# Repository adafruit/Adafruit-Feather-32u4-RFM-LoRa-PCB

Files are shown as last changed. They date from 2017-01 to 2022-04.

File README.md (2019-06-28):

## Adafruit Feather 32u4 RFM LoRa Radios PCB

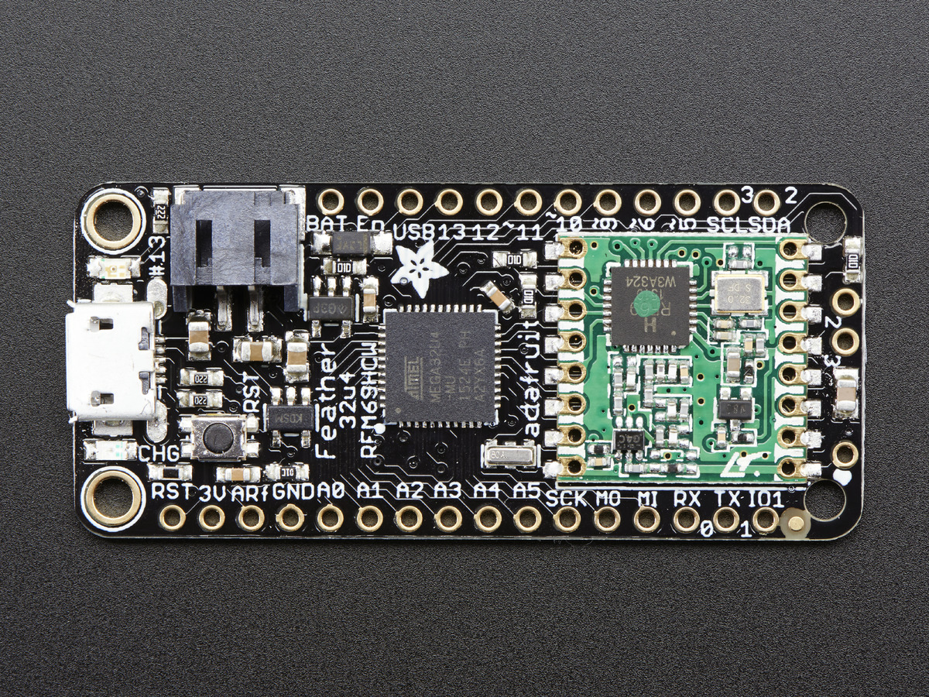
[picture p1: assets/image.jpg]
<br/>
Click below to purchase one from the Adafruit shop

PCB files for the Adafruit Feather 32u4 RFM69 and LoRa Radio. Format is EagleCAD schematic and board layout

For more details, check out the product pages at
* RFM69HCW Packet Radio - 868 or 915 MHz https://www.adafruit.com/product/3076
* RFM69HCW Packet Radio - 433MHz https://www.adafruit.com/product/3077
* RFM95 LoRa Radio- 868 or 915 MHz https://www.adafruit.com/product/3078
* RFM96 LoRa Radio - 433MHz https://www.adafruit.com/product/3079

### Description

We call these RadioFruits, our take on an microcontroller packet radio transceiver with built in USB and battery charging. Its an Adafruit Feather 32u4 with a radio module cooked in! Great for making wireless networks that can go further than 2.4GHz 802.15.4 and similar, are more flexible than Bluetooth LE and without the high power requirements of WiFi.

Feather is the new development board from Adafruit, and like its namesake it is thin, light, and lets you fly! We designed Feather to be a new standard for portable microcontroller cores.

### License

Adafruit invests time and resources providing this open source design, please support Adafruit and open-source hardware by purchasing products from [Adafruit](https://www.adafruit.com)!

Designed by Limor Fried/Ladyada for Adafruit Industries.

Creative Commons Attribution/Share-Alike, all text above must be included in any redistribution. See license.txt for additional details.

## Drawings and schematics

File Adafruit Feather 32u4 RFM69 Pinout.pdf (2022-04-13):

# Adafruit Feather 32u4 RFM69 433/900MHz

# https://www.adafruit.com/products/3076

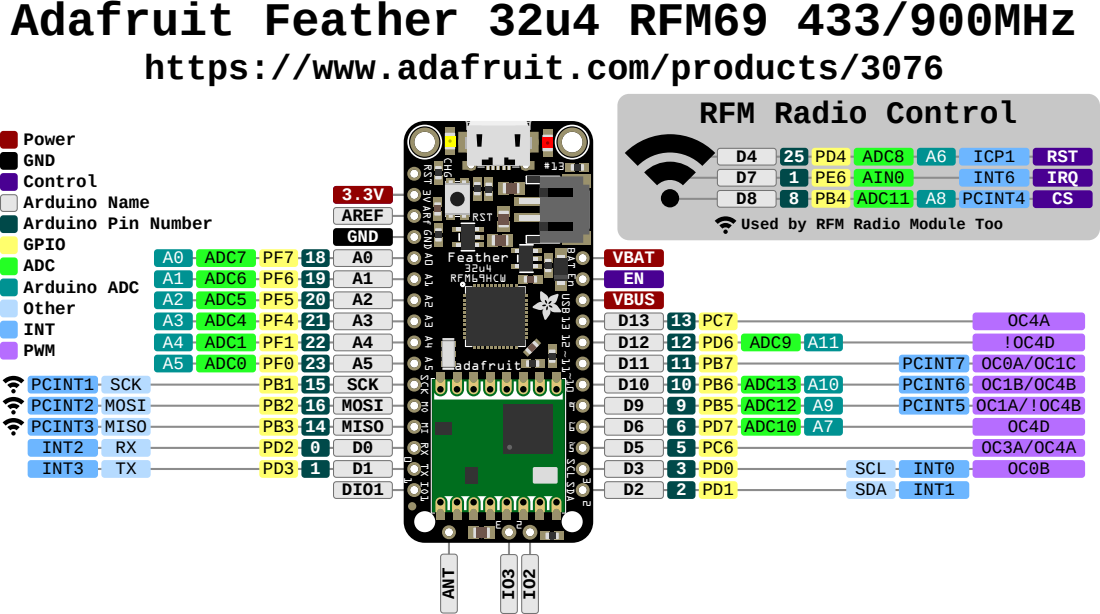
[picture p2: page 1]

Used by RFM Radio Module Too

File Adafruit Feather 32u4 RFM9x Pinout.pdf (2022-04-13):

# Adafruit Feather 32u4 RFM9x LoRa

# https://www.adafruit.com/products/3078

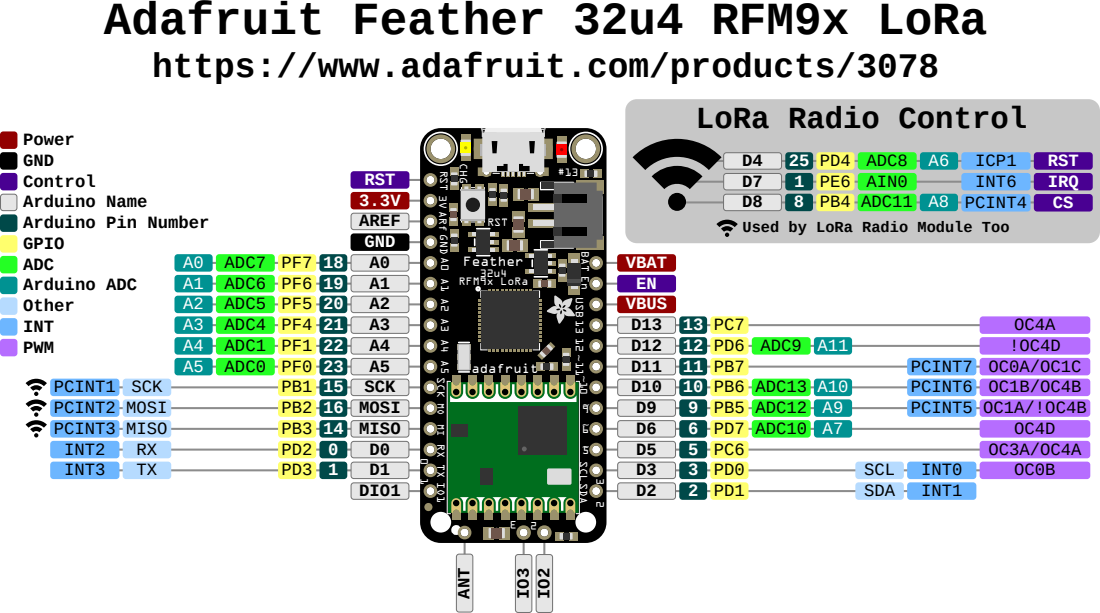
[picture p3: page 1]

Used by LoRa Radio Module Too

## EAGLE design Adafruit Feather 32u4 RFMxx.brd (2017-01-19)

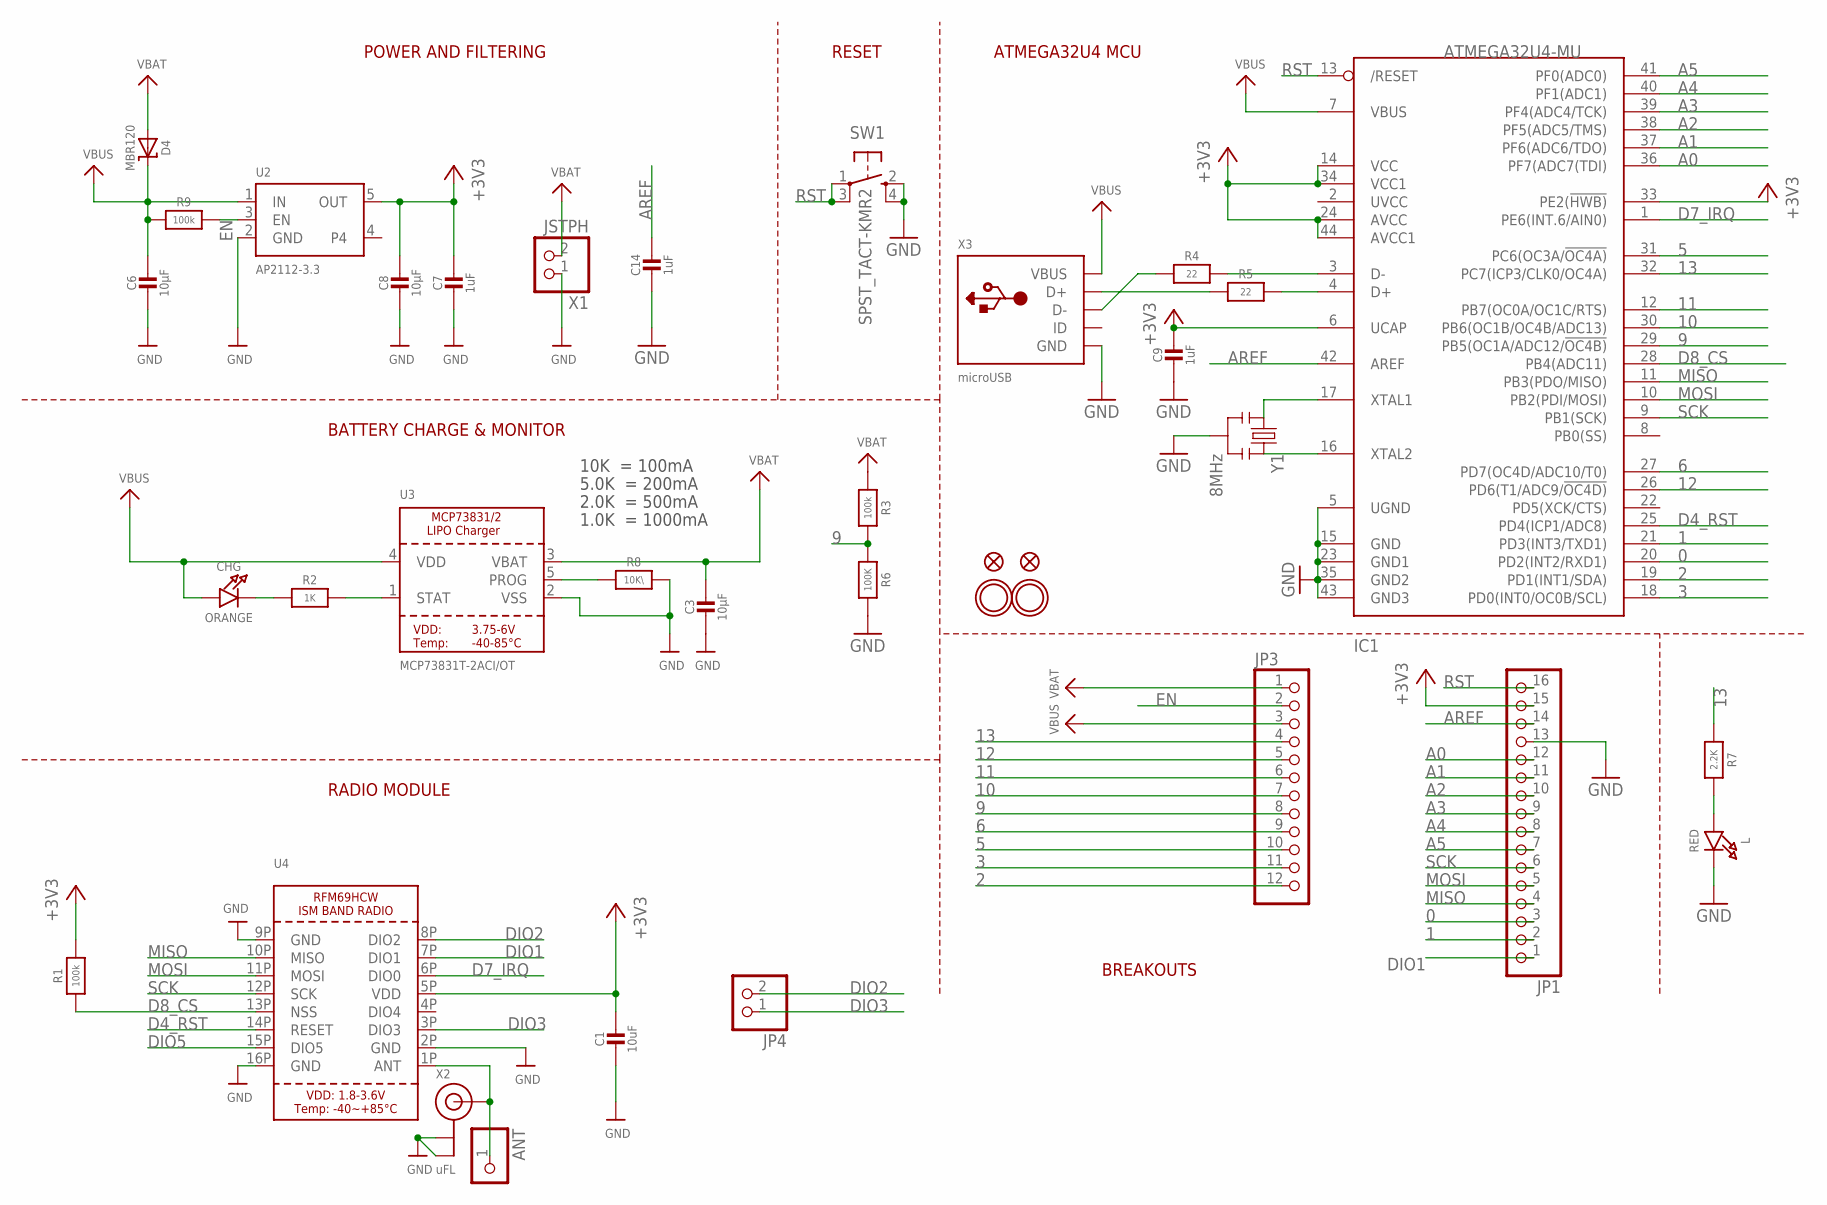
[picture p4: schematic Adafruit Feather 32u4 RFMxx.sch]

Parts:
ANT: HEADER-1X1ROUND; 1X01_ROUND
C1: 10uF; 0805-NO
C3, C6, C8: 10µF; 0805-NO
C7, C14: 1uF; 0603-NO
C9: 1uF; _0603MP
CHG: ORANGE; CHIPLED_0805_NOOUTLINE
D4: MBR120; SOD-123
IC1: ATMEGA32U4-MU; TQFN44_7MM
JP1: HEADER-1X16ROUND; 1X16_ROUND
JP3: HEADER-1X12; 1X12_ROUND
JP4: HEADER-1X2ROUND; 1X02_ROUND
L: RED; CHIPLED_0805_NOOUTLINE
R1, R3, R9: 100k; 0603-NO
R2: 1K; 0603-NO
R4, R5: 22; 0603-NO
R6: 100K; 0603-NO
R7: 2.2K; 0603-NO
R8: 10K\; 0603-NO
SW1: SPST_TACT-KMR2; KMR2
U2: AP2112-3.3; SOT23-5
U3: MCP73831T-2ACI/OT; SOT23-5
U4: RFM69HCW_SMT; RFMHCW_SMT
U$31, U$32: MOUNTINGHOLE2.5; MOUNTINGHOLE_2.5_PLATED
U$34, U$35: FIDUCIAL""; FIDUCIAL_1MM
X1: JSTPH; JSTPH2
X2: uFL; U.FL
X3: microUSB; 4UCONN_20329_V2
Y1: 8MHz; RESONATOR-SMD

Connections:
0: IC1.20 (PD2(INT2/RXD1)), JP1.3
1: IC1.21 (PD3(INT3/TXD1)), JP1.2
2: IC1.19 (PD1(INT1/SDA)), JP3.12
3: IC1.18 (PD0(INT0/OC0B/SCL)), JP3.11
5: IC1.31 (PC6(OC3A/!OC4A)), JP3.10
6: IC1.27 (PD7(OC4D/ADC10/T0)), JP3.9
9: IC1.29 (PB5(OC1A/ADC12/!OC4B)), JP3.8, R3.2, R6.1
10: IC1.30 (PB6(OC1B/OC4B/ADC13)), JP3.7
11: IC1.12 (PB7(OC0A/OC1C/RTS)), JP3.6
12: IC1.26 (PD6(T1/ADC9/!OC4D)), JP3.5
13: IC1.32 (PC7(ICP3/CLK0/OC4A)), JP3.4, R7.1
+3V3: C1.1, C7.1, C8.1, C9.1, IC1.6 (UCAP), IC1.14 (VCC), IC1.24 (AVCC), IC1.33 (PE2(!HWB)), IC1.34 (VCC1), IC1.44 (AVCC1), JP1.15, R1.2, U2.5 (OUT), U4.5P (VDD)
A0: IC1.36 (PF7(ADC7(TDI)), JP1.12
A1: IC1.37 (PF6(ADC6/TDO)), JP1.11
A2: IC1.38 (PF5(ADC5/TMS)), JP1.10
A3: IC1.39 (PF4(ADC4/TCK)), JP1.9
A4: IC1.40 (PF1(ADC1)), JP1.8
A5: IC1.41 (PF0(ADC0)), JP1.7
ANT: ANT.1, U4.1P (ANT), X2.3 (SIGNAL)
AREF: C14.1, IC1.42 (AREF), JP1.14
D4_RST: IC1.25 (PD4(ICP1/ADC8)), U4.14P (RESET)
D7_IRQ: IC1.1 (PE6(INT.6/AIN0)), U4.6P (DIO0)
D8_CS: IC1.28 (PB4(ADC11)), R1.1, U4.13P (NSS)
D+: IC1.4 (D+), R5.2
D-: IC1.3 (D-), R4.2
DIO1: JP1.1, U4.7P (DIO1)
DIO2: JP4.2, U4.8P (DIO2)
DIO3: JP4.1, U4.3P (DIO3)
DIO5: U4.15P (DIO5)
EN: JP3.2, R9.2, U2.3 (EN)
GND: C1.2, C3.2, C6.2, C7.2, C8.2, C9.2, C14.2, IC1.5 (UGND), IC1.15 (GND), IC1.23 (GND1), IC1.35 (GND2), IC1.43 (GND3), JP1.13, L.C, R6.2, R8.2, SW1.2 (S), SW1.4 (S1), U2.2 (GND), U3.2 (VSS), U4.2P (GND), U4.9P (GND), U4.16P (GND), X1.1, X2.1 (GND), X2.2 (GND), X3.BASE@1 (GND), X3.BASE@2 (GND), X3.GND, X3.SPRT@1 (GND), X3.SPRT@2 (GND), X3.SPRT@3 (GND), X3.SPRT@4 (GND), Y1.2
MISO: IC1.11 (PB3(PDO/MISO)), JP1.4, U4.10P (MISO)
MOSI: IC1.10 (PB2(PDI/MOSI)), JP1.5, U4.11P (MOSI)
unnamed: CHG.C, R2.1
unnamed: L.A, R7.2
unnamed: R2.2, U3.1 (STAT)
unnamed: R8.1, U3.5 (PROG)
unnamed: IC1.16 (XTAL2), Y1.3
unnamed: IC1.17 (XTAL1), Y1.1
unnamed: R5.1, X3.D+
unnamed: R4.1, X3.D-
RST: IC1.13 (/RESET), JP1.16, SW1.1, SW1.3 (P1)
SCK: IC1.9 (PB1(SCK)), JP1.6, U4.12P (SCK)
VBAT: C3.1, D4.A, JP3.1, R3.1, U3.3 (VBAT), X1.2
VBUS: C6.1, CHG.A, D4.C, IC1.7 (VBUS), JP3.3, R9.1, U2.1 (IN), U3.4 (VDD), X3.VBUS

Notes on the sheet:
POWER AND FILTERING
RESET
ATMEGA32U4 MCU
10K = 100mA
5.0K = 200mA
2.0K = 500mA
1.0K = 1000mA
BATTERY CHARGE & MONITOR
BREAKOUTS
RADIO MODULE

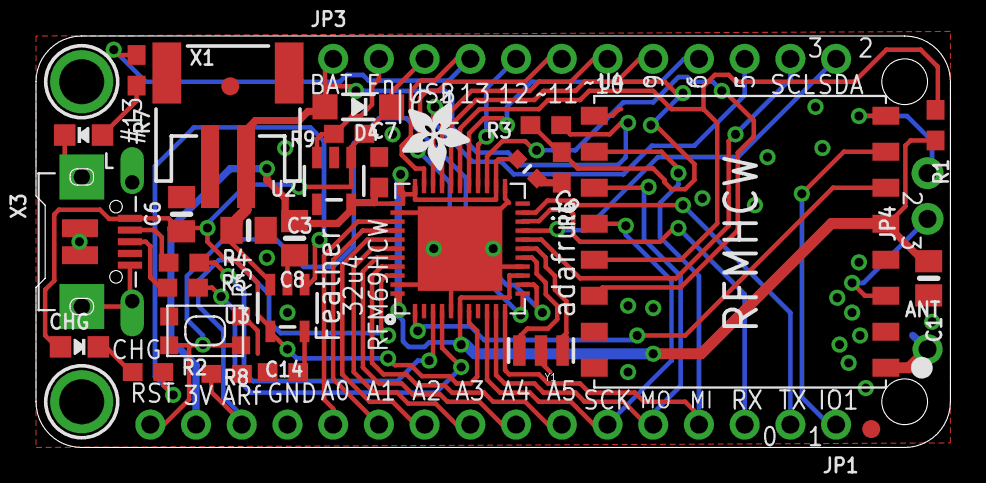
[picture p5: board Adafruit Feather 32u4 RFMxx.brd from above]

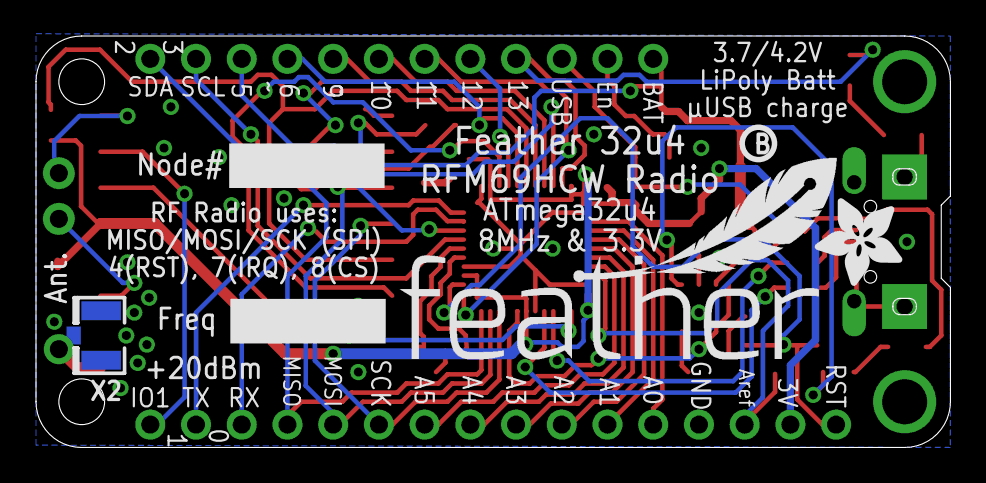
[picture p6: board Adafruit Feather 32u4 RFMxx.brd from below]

Board: 2 copper layers, 50.8 x 22.9 mm, 40 parts (4 on the bottom side), 44 nets.

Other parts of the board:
U$4: ADAFRUIT_5MM
U$5: FEATHERLOGO
U$6: PCBFEAT-REV-040
U$7: ADAFRUIT_3.5MM

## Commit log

2016-12-09 fix one routed but still DRC'ing trace
    [Adafruit Feather 32u4 RFMxx.brd]
2017-01-19 fix broken #8 trace
    [Adafruit Feather 32u4 RFMxx.brd, Adafruit Feather 32u4 RFMxx.sch]

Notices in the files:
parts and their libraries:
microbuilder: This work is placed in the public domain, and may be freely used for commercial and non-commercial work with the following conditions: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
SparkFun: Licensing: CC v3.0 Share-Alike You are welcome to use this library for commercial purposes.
